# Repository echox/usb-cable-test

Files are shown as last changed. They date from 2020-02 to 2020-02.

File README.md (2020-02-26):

# USB Cable Tester
This is a simple tester for USB cables with USB A and Micro USB B.

## Usage

### Cable test
Connect a cable to both ends of the tester. All four LEDs should light up.

If a LED isn't lighting up the corresponding wire might be broken or not connected.
Some cables come without the wires for data transmitting. These type of cables is only suiteable for slow charging a device and can be easily detected if the LEDs for D+ and D- are not connected.

### Battery test
To check if the battery is working disconnect any connected cable.
Press the button. All LEDs should light up.

### Testpads
You can also use the testpads for checking the data lines of your cable.
Connect a probe of your multimeter to TP1 and then check every other testpad for a connection.

## Build
The build is straightforward but contains SMD components with a small footprint (0603).
See the [bom.md](bom.md) for details.

The board and schematics were created with [https://kicad-pcb.org/](KiCad) and can be found in the `board/` directory.

I used OSHPark for manufactoring, you can order this version directly at //TODO add OSHPark link 

Have fun.

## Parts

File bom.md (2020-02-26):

# Bill of Materials

| Reference | Part | Value | Package | Count
|---|---|---|---|---
| BT1 | Battery Holder | 3V | CR2032  | 1x
| SW1 | Bat Test Button | | SMD | 1x
| USB_A | USB A Socket | | SMD | 1x
| USB_B_Micro | USB B Micro Socket  | | SMD | 1x
| R1, R2, R3, R4 | LED Resistors | 51 Ohm | 0603 | 4x
| LED1, LED2, LED3, LED4 | Green Status LEDs | 2V, 20mA | 0603 | 4x
| D1, D2, D3, D4 | Test Button Diodes  | 1n4148 | SOD-323 | 4x

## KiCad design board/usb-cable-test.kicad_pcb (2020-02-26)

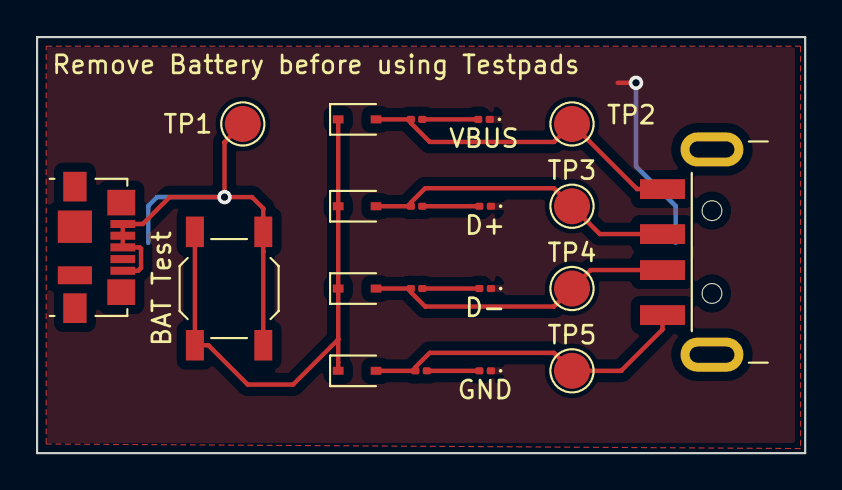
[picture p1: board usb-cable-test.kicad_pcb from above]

Board: 2 copper layers, 42.7 x 23.1 mm, 21 parts (1 on the bottom side), 11 nets.

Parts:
CR2032: Battery_Cell; BatteryHolder_Keystone_1060_1x2032
D1, D2, D3, D4: 1n4148; D_SOD-323
D+: LED; D_0201_0603Metric
D-: LED; D_0201_0603Metric
GND: LED; D_0201_0603Metric
J1: USB_A; USB_A_CNCTech_1001-011-01101_Horizontal
J2: USB_B_Micro; USB_Micro-B_Molex_47346-0001
R1, R2, R3, R4: 5,1; R_0201_0603Metric
SW1: BAT Test; SW_SPST_TL3342
TP1, TP2, TP3, TP4, TP5: TestPoint; TestPoint_Pad_D2.0mm
VBUS: LED; D_0201_0603Metric

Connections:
unnamed: CR2032.1, J2.1, J2.2, J2.3, J2.5, SW1.1, TP1.1
unnamed: CR2032.2, D+.1, D-.1, GND.1, VBUS.1
unnamed: D1.1, D2.1, D3.1, D4.1, SW1.2
unnamed: D1.2, J1.1, R1.2, TP2.1
unnamed: D2.2, J1.2, R2.2, TP3.1
unnamed: D3.2, J1.3, R3.2, TP4.1
unnamed: D4.2, J1.4, R4.2, TP5.1
unnamed: R1.1, VBUS.2
unnamed: D+.2, R2.1
unnamed: D-.2, R3.1
unnamed: GND.2, R4.1

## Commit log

2020-02-26 init kicad files
    [usb-cable-test.kicad_pcb, usb-cable-test.sch]
2020-02-26 added bom
2020-02-26 bom table fix
